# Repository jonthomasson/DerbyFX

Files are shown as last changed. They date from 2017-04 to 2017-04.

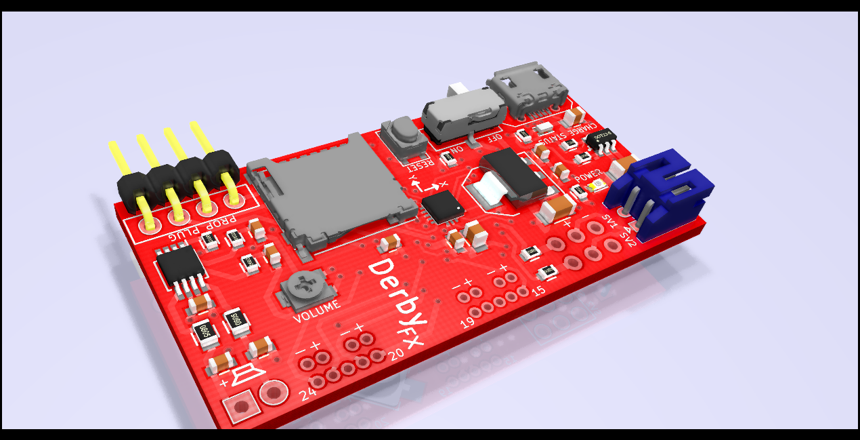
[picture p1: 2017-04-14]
rev1.b/derbyFX_raytrace.png

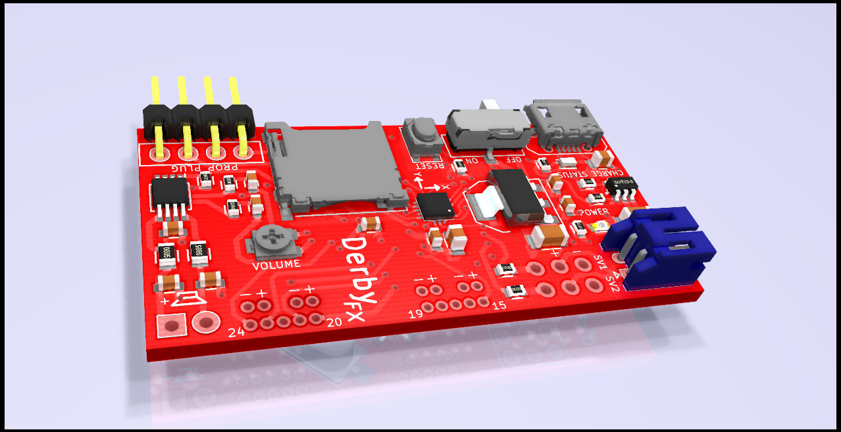
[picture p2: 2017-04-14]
rev1.b/derbyFX_rev1.b.png

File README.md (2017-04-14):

# DerbyFX
This small board provides a development platform for a pinewood derby car. It sports an accelerometer, an sd card, a charge circuit for an external lithium ion battery, an audio amp, 2 servo plugs, a speaker connector, and 10 gpio pins. At the heart of the board is a Parallax Propeller microcontroller.

![CPLD running in breadboard](https://lh3.googleusercontent.com/XKKODQA45qIu_XWEh1ipbHdZi0rYT_jDOUO9jJZsp1Ay5FmV7U-XDJ-tHK5IJP2ZgFuQk_qfYUtz5T6PSdiaZT0pmwx6YwFBaJhmt29JHCF6nIpZZk6bQHzHcNKXj_aoYBd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)

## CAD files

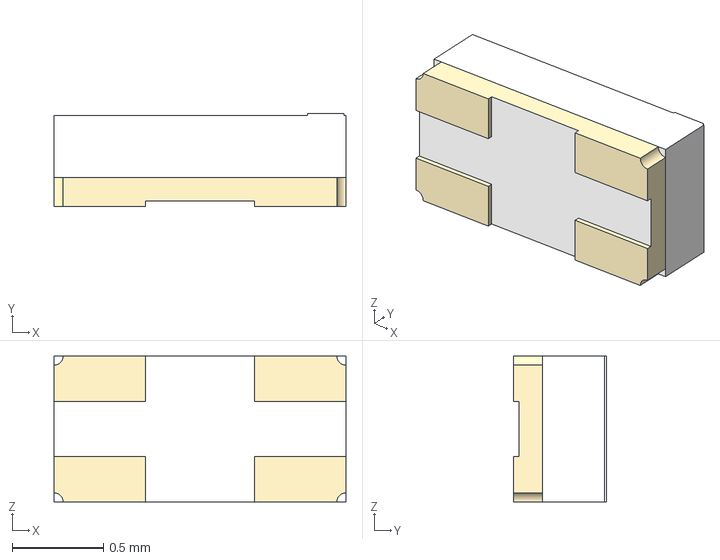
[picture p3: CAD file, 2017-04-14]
rev1.b/3dmodels/HSMF_C16X.step
1.60 x 0.51 x 0.8 mm

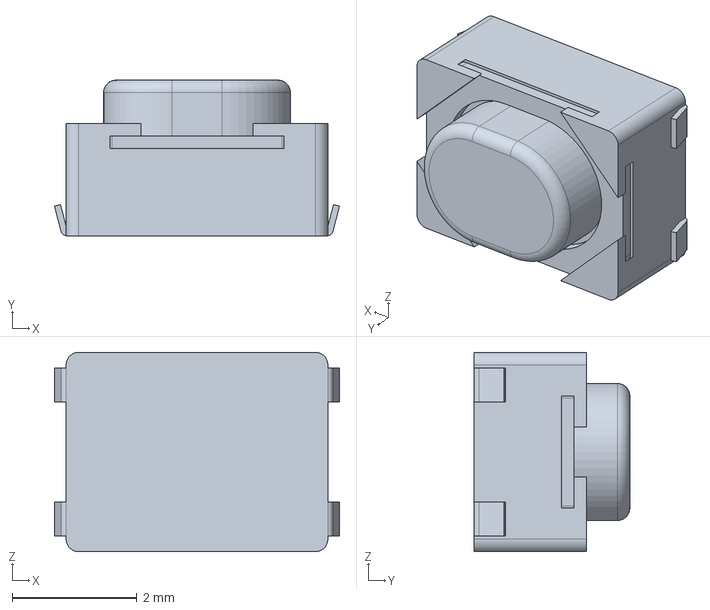
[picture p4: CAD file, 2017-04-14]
rev1.b/3dmodels/PTS810.stp
4.58 x 2.50 x 3.20 mm

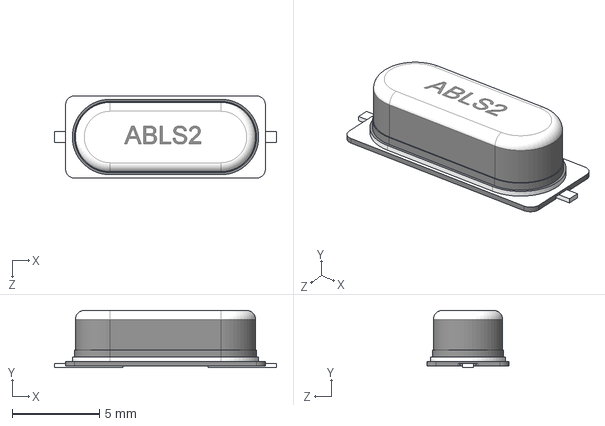
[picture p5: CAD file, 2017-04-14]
rev1.b/3dmodels/ABLS2.STEP
12.7 x 3.27 x 4.70 mm

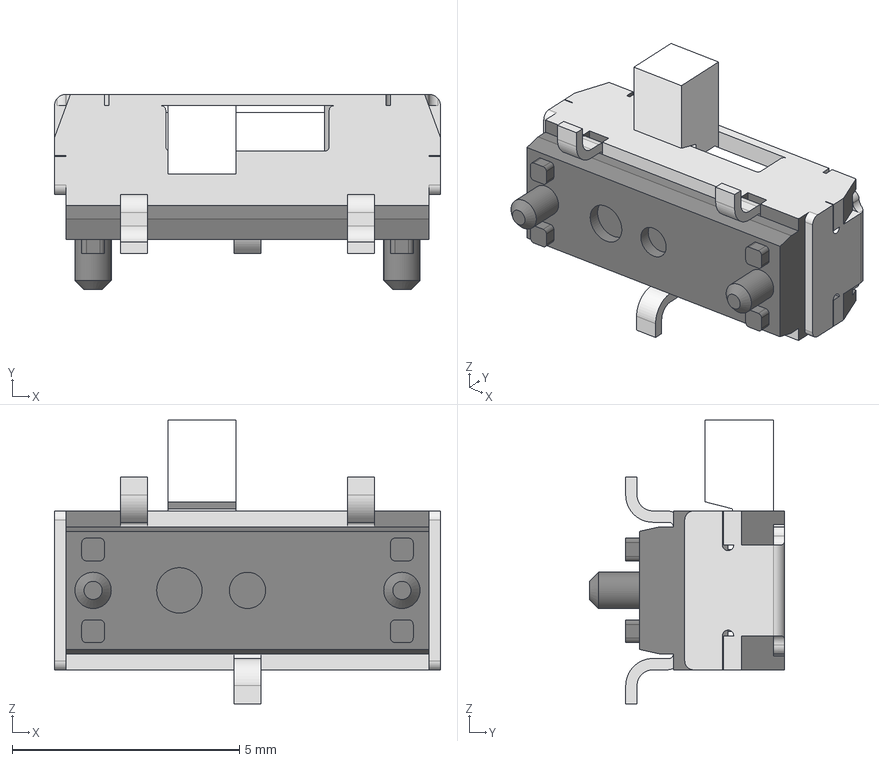
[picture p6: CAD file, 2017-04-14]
rev1.b/3dmodels/CL-SB-12B-11T.stp
8.50 x 4.30 x 6.25 mm
_12B-11_c
_2Side setting_s

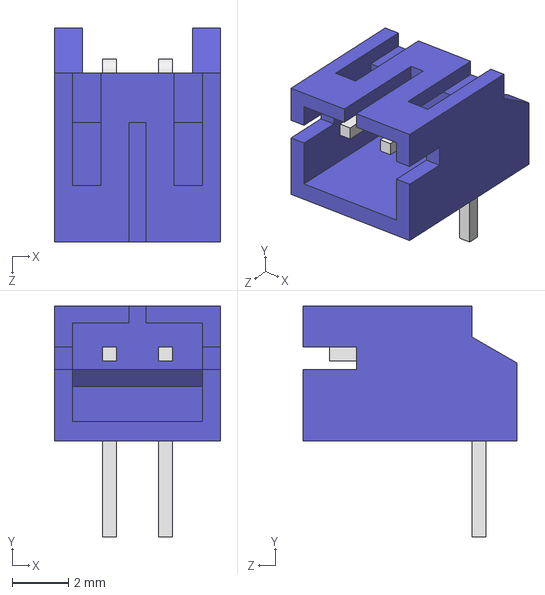
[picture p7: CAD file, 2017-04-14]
rev1.b/3dmodels/S2B-PH-K-S.STEP
5.90 x 8.20 x 7.60 mm

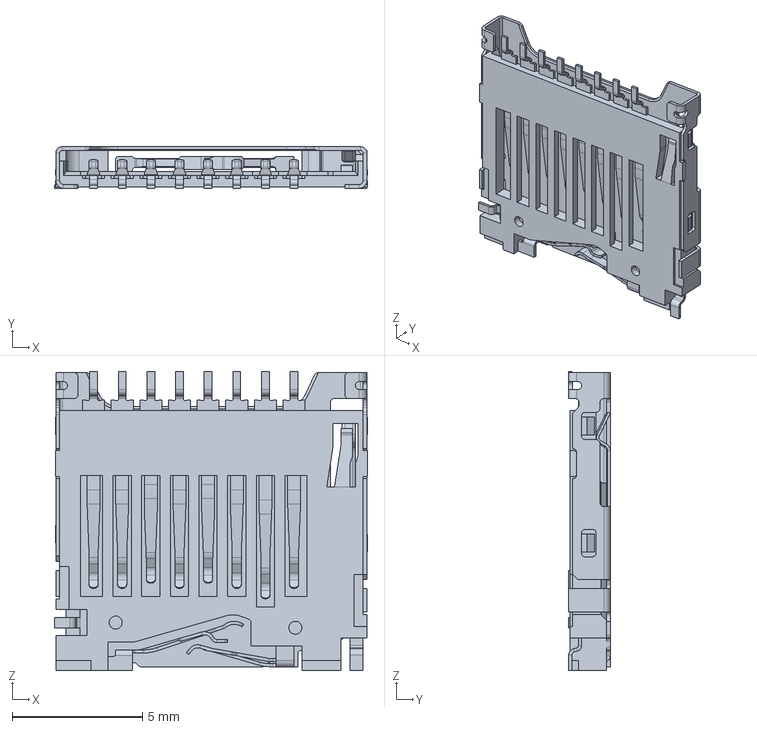
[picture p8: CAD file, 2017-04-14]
rev1.b/3dmodels/1140084168-revB.stp
12.0 x 1.60 x 11.5 mm

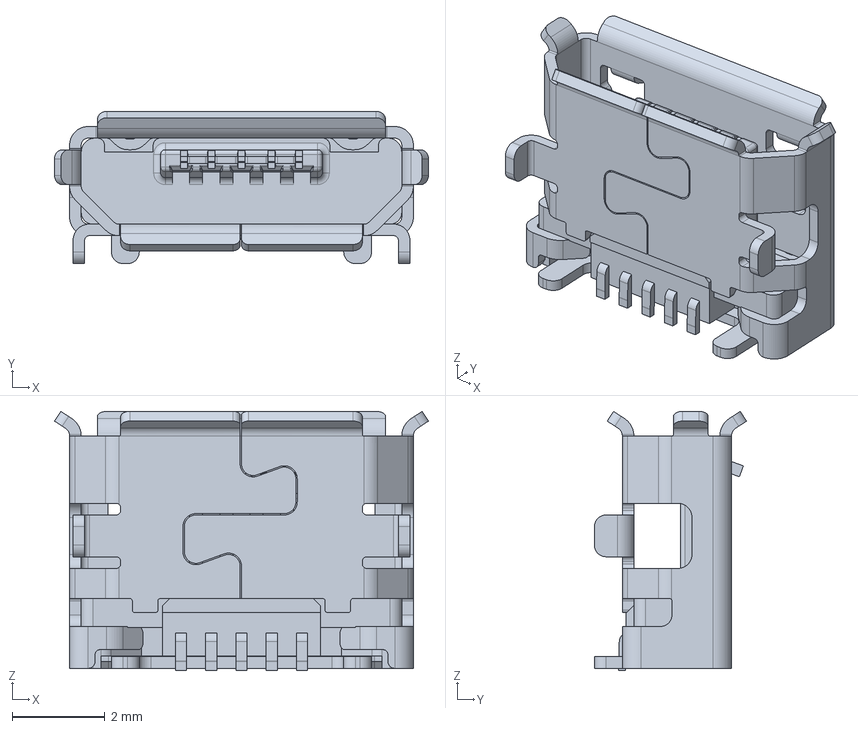
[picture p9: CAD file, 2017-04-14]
rev1.b/3dmodels/10118194c.stp
8.05 x 3.27 x 5.58 mm

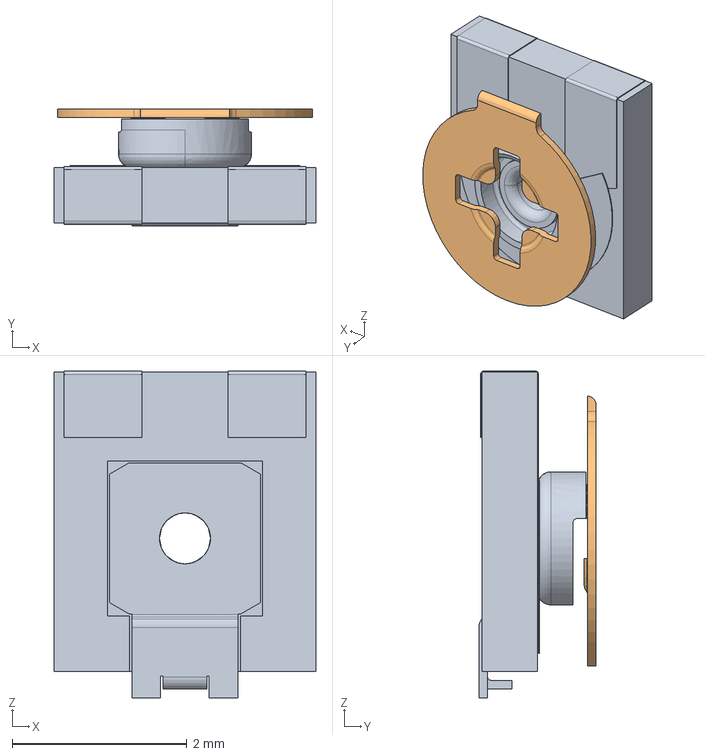
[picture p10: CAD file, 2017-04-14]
rev1.b/3dmodels/3303X003.stp
3.00 x 1.35 x 3.75 mm

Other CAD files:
rev1.b/3dmodels/User Library-HSMF-C16x.STEP
rev1.b/3dmodels/DM3D-SF.stp
rev1.b/3dmodels/ABLS2_revb.step
rev1.b/3dmodels/S2B_PH_K_S.step

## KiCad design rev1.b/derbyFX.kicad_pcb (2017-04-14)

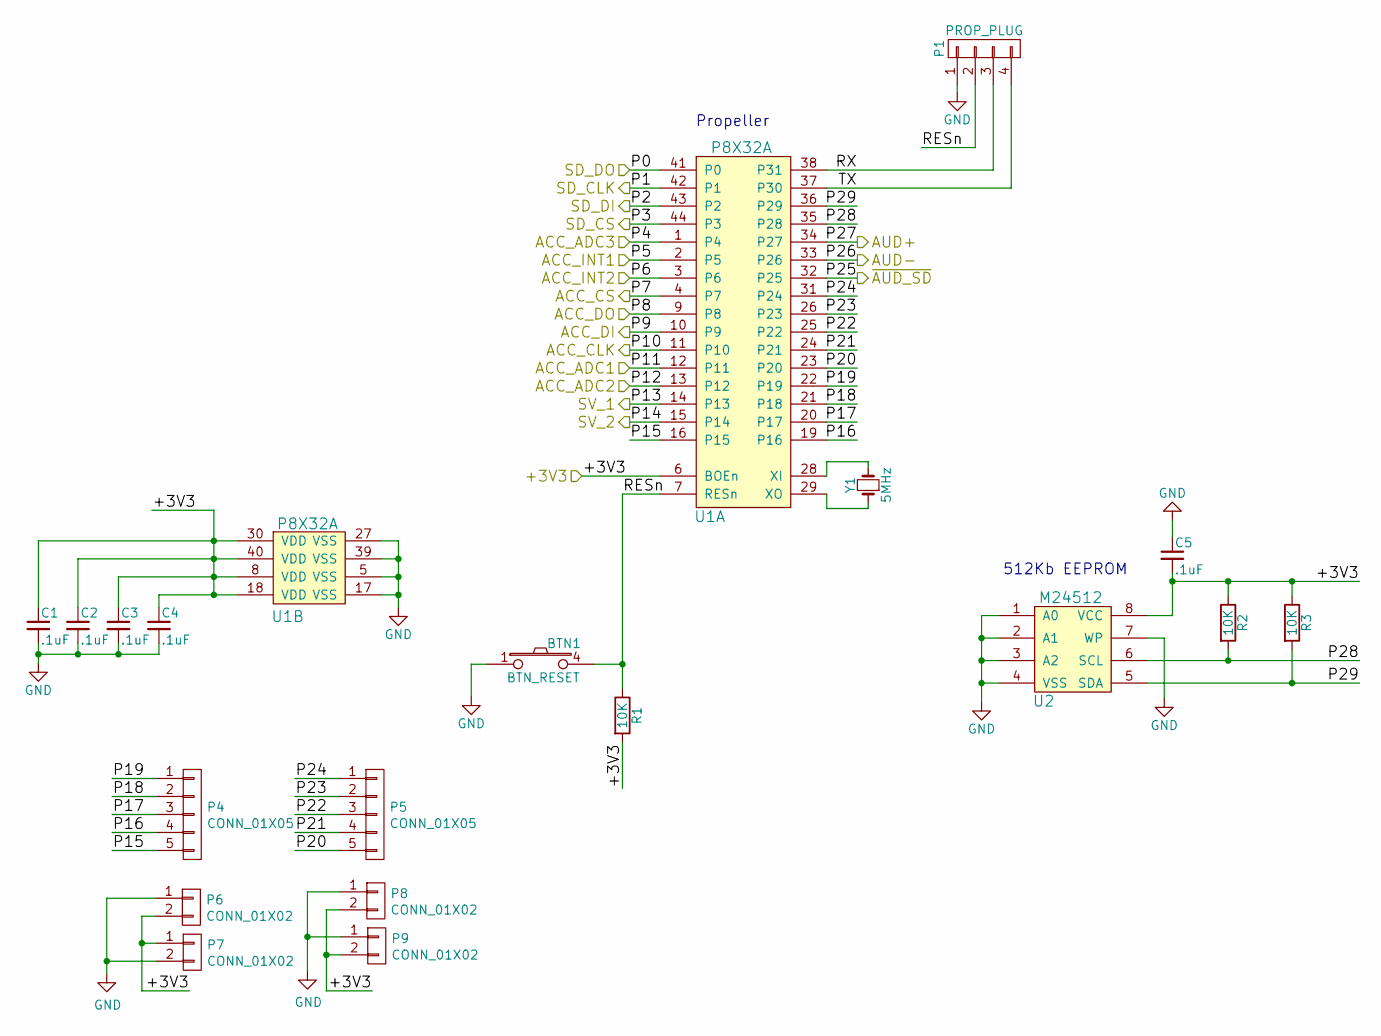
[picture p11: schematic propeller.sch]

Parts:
BTN1: BTN_RESET; SWITCH_PTS810
C1, C2, C3, C4, C5: .1uF; C_0603
P1: PROP_PLUG; Pin_Header_Angled_1x04
P4, P5: CONN_01X05; CONN_1_X_5_MINI
P6, P7, P8, P9: CONN_01X02; CONN_1_X_2_MINI
R1, R2, R3: 10K; R_0603
U1: P8X32A; LQFP-44_10x10mm_Pitch0.8mm
U2: M24512; SOIC-8_3.9x4.9mm_Pitch1.27mm
Y1: 5MHz; Crystal_HC49-SD_SMD

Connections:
/Sheet58820796/+3V3: C1.1, C2.1, C3.1, C4.1, C5.2, P6.2, P7.1, P8.2, P9.2, R1.2, R2.1, R3.1, U1.6 (BOEn), U1.8 (VDD), U1.18 (VDD), U1.30 (VDD), U1.40 (VDD), U2.8 (VCC); also elsewhere on the board
/Sheet58820796/ACC_ADC1: U1.12 (P11); also elsewhere on the board
/Sheet58820796/ACC_ADC2: U1.13 (P12); also elsewhere on the board
/Sheet58820796/ACC_ADC3: U1.1 (P4); also elsewhere on the board
/Sheet58820796/ACC_CLK: U1.11 (P10); also elsewhere on the board
/Sheet58820796/ACC_CS: U1.4 (P7); also elsewhere on the board
/Sheet58820796/ACC_DI: U1.10 (P9); also elsewhere on the board
/Sheet58820796/ACC_DO: U1.9 (P8); also elsewhere on the board
/Sheet58820796/ACC_INT1: U1.2 (P5); also elsewhere on the board
/Sheet58820796/ACC_INT2: U1.3 (P6); also elsewhere on the board
/Sheet58820796/AUD+: U1.34 (P27); also elsewhere on the board
/Sheet58820796/AUD-: U1.33 (P26); also elsewhere on the board
/Sheet58820796/P15: P4.5, U1.16 (P15)
/Sheet58820796/P16: P4.4, U1.19 (P16)
/Sheet58820796/P17: P4.3, U1.20 (P17)
/Sheet58820796/P18: P4.2, U1.21 (P18)
/Sheet58820796/P19: P4.1, U1.22 (P19)
/Sheet58820796/P20: P5.5, U1.23 (P20)
/Sheet58820796/P21: P5.4, U1.24 (P21)
/Sheet58820796/P22: P5.3, U1.25 (P22)
/Sheet58820796/P23: P5.2, U1.26 (P23)
/Sheet58820796/P24: P5.1, U1.31 (P24)
/Sheet58820796/P28: R2.2, U1.35 (P28), U2.6 (SCL)
/Sheet58820796/P29: R3.2, U1.36 (P29), U2.5 (SDA)
/Sheet58820796/RESn: BTN1.4, P1.2, R1.1, U1.7 (RESn)
/Sheet58820796/RX: P1.3, U1.38 (P31)
/Sheet58820796/SD_CLK: U1.42 (P1); also elsewhere on the board
/Sheet58820796/SD_CS: U1.44 (P3); also elsewhere on the board
/Sheet58820796/SD_DI: U1.43 (P2); also elsewhere on the board
/Sheet58820796/SD_DO: U1.41 (P0); also elsewhere on the board
/Sheet58820796/SV_1: U1.14 (P13); also elsewhere on the board
/Sheet58820796/SV_2: U1.15 (P14); also elsewhere on the board
/Sheet58820796/TX: P1.4, U1.37 (P30)
/Sheet58820796/~AUD_SD: U1.32 (P25); also elsewhere on the board
GND: BTN1.1, C1.2, C2.2, C3.2, C4.2, C5.1, P1.1, P6.1, P7.2, P8.1, P9.1, U1.5 (VSS), U1.17 (VSS), U1.27 (VSS), U1.39 (VSS), U2.1 (A0), U2.2 (A1), U2.3 (A2), U2.4 (VSS), U2.7 (WP); also elsewhere on the board
unnamed: U1.28 (XI), Y1.2
unnamed: U1.29 (XO), Y1.1

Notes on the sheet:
512Kb EEPROM
Propeller

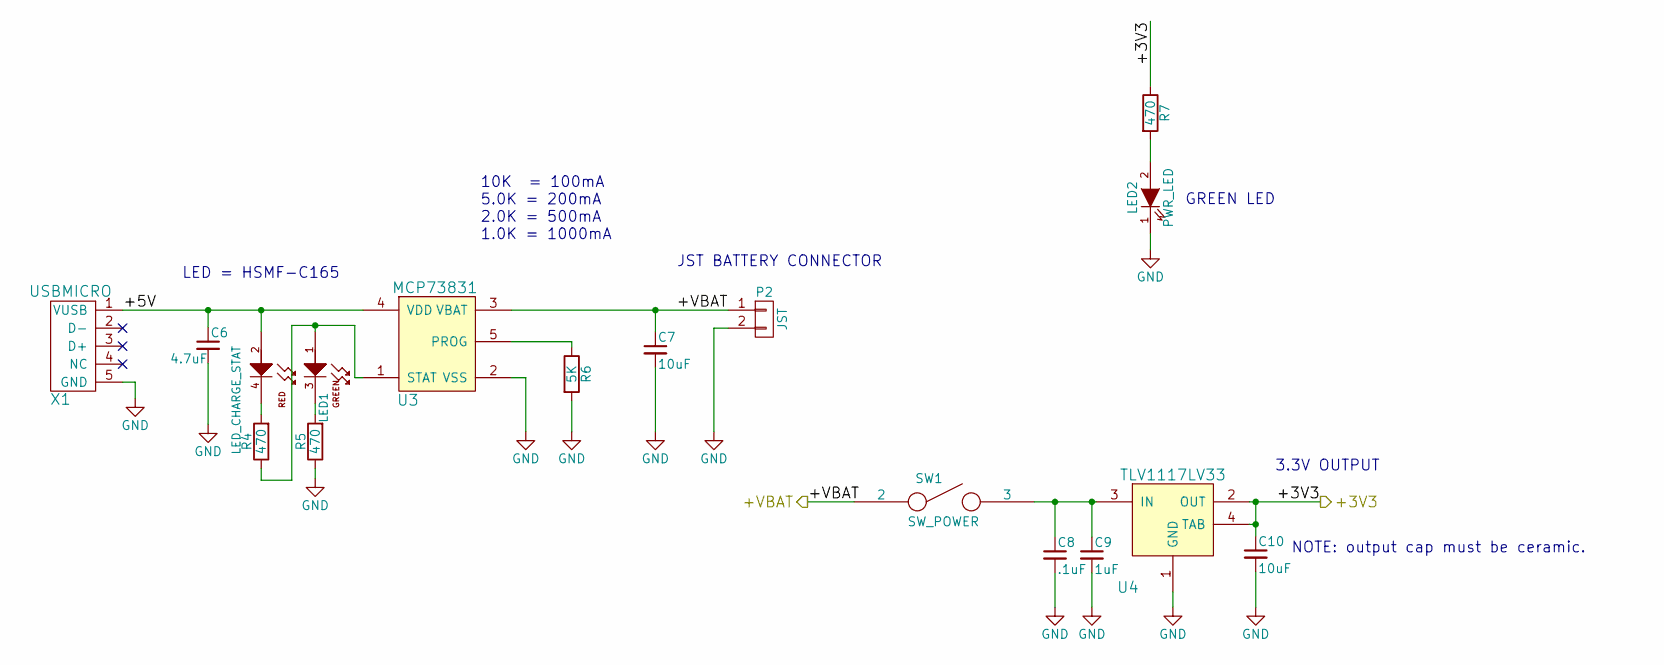
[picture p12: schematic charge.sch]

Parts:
C6: 4.7uF; C_0805
C7, C10: 10uF; C_1206
C8: .1uF; C_0603
C9: 1uF; C_0603
LED1: LED_CHARGE_STAT; LED_0603_HSMF_C165
LED2: PWR_LED; LED_0603
P2: JST; JST_PH_S2B-PH-K_02x2.00mm_Angled
R4, R5, R7: 470; R_0603
R6: 5K; R_0603
SW1: SW_POWER; SWITCH_CL_SB_12B
U3: MCP73831; SOT-23-5
U4: TLV1117LV33; SOT-223
X1: USBMICRO; MICRO_USB_10118194

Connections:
/Sheet588423CD/+5V: C6.1, LED1.2 (ANODE_RED), U3.4 (VDD), X1.1 (VUSB)
/Sheet588423CD/+VBAT: C7.1, P2.1, SW1.2, U3.3 (VBAT); also elsewhere on the board
/Sheet58820796/+3V3: C10.1, R7.1, U4.2 (OUT), U4.4 (TAB); also elsewhere on the board
GND: C6.2, C7.2, C8.2, C9.2, C10.2, LED2.1 (K), P2.2, R5.1, R6.2, U3.2 (VSS), U4.1 (GND), X1.5 (GND); also elsewhere on the board
unnamed: C8.1, C9.1, SW1.3, U4.3 (IN)
unnamed: LED1.1 (ANODE_GREEN), R4.1, U3.1 (STAT)
unnamed: LED1.3 (CATHODE_GREEN), R5.2
unnamed: LED1.4 (CATHODE_RED), R4.2
unnamed: LED2.2 (A), R7.2
unnamed: R6.1, U3.5 (PROG)

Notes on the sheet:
10K = 100mA 5.0K = 200mA 2.0K = 500mA 1.0K = 1000mA
JST BATTERY CONNECTOR
3.3V OUTPUT
NOTE: output cap must be ceramic.
GREEN LED
LED = HSMF-C165

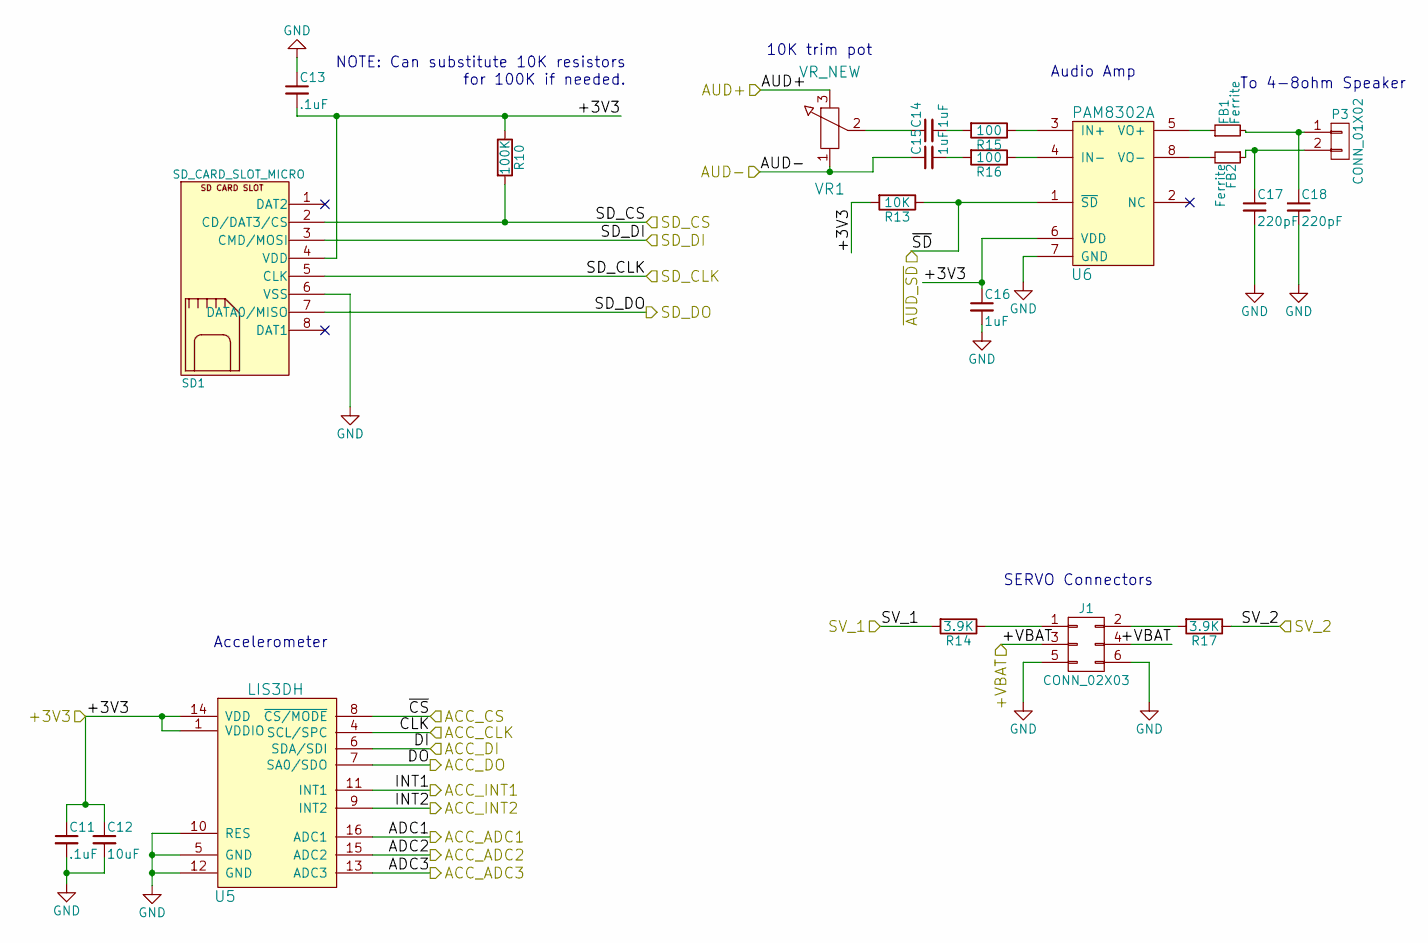
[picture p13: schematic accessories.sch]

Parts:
C11, C13: .1uF; C_0603
C12: 10uF; C_0805
C14, C15, C16: 1uF; C_0603
C17, C18: 220pF; C_0603
FB1, FB2: Ferrite; R_0805
J1: CONN_02X03; Pin_Header_Straight_2x03
P3: CONN_01X02; Pin_Header_Straight_1x02
R10: 100K; R_0603
R13: 10K; R_0603
R14, R17: 3.9K; R_0603
R15, R16: 100; R_0603
SD1: SD_CARD_SLOT_MICRO; MICRO_SD_1140084168
U5: LIS3DH; LGA_16_3x3
U6: PAM8302A; MSOP-8_3x3mm_Pitch0.65mm
VR1: VR_NEW; BOURNS_3303W

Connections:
/Sheet588423CD/+VBAT: J1.3, J1.4; also elsewhere on the board
/Sheet58820796/+3V3: C11.1, C12.1, C13.2, C16.1, R10.1, R13.2, SD1.4 (VDD), U5.1 (VDDIO), U5.14 (VDD), U6.6 (VDD); also elsewhere on the board
/Sheet58820796/ACC_ADC1: U5.16 (ADC1); also elsewhere on the board
/Sheet58820796/ACC_ADC2: U5.15 (ADC2); also elsewhere on the board
/Sheet58820796/ACC_ADC3: U5.13 (ADC3); also elsewhere on the board
/Sheet58820796/ACC_CLK: U5.4 (SCL/SPC); also elsewhere on the board
/Sheet58820796/ACC_CS: U5.8 (~CS/MODE); also elsewhere on the board
/Sheet58820796/ACC_DI: U5.6 (SDA/SDI); also elsewhere on the board
/Sheet58820796/ACC_DO: U5.7 (SA0/SDO); also elsewhere on the board
/Sheet58820796/ACC_INT1: U5.11 (INT1); also elsewhere on the board
/Sheet58820796/ACC_INT2: U5.9 (INT2); also elsewhere on the board
/Sheet58820796/AUD+: VR1.3; also elsewhere on the board
/Sheet58820796/AUD-: C15.1, VR1.1; also elsewhere on the board
/Sheet58820796/SD_CLK: SD1.5 (CLK); also elsewhere on the board
/Sheet58820796/SD_CS: R10.2, SD1.2 (CD/DAT3/CS); also elsewhere on the board
/Sheet58820796/SD_DI: SD1.3 (CMD/MOSI); also elsewhere on the board
/Sheet58820796/SD_DO: SD1.7 (DATA0/MISO); also elsewhere on the board
/Sheet58820796/SV_1: R14.2; also elsewhere on the board
/Sheet58820796/SV_2: R17.1; also elsewhere on the board
/Sheet58820796/~AUD_SD: R13.1, U6.1 (~SD); also elsewhere on the board
GND: C11.2, C12.2, C13.1, C16.2, C17.2, C18.2, J1.5, J1.6, SD1.6 (VSS), U5.5 (GND), U5.10 (RES), U5.12 (GND), U6.7 (GND); also elsewhere on the board
unnamed: C14.1, VR1.2
unnamed: C14.2, R15.2
unnamed: C15.2, R16.2
unnamed: C17.1, FB2.1, P3.2
unnamed: C18.1, FB1.2, P3.1
unnamed: FB1.1, U6.5 (VO+)
unnamed: FB2.2, U6.8 (VO-)
unnamed: J1.1, R14.1
unnamed: J1.2, R17.2
unnamed: R15.1, U6.3 (IN+)
unnamed: R16.1, U6.4 (IN-)

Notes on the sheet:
NOTE: Can substitute 10K resistors for 100K if needed.
To 4-8ohm Speaker
10K trim pot
SERVO Connectors
Accelerometer
Audio Amp

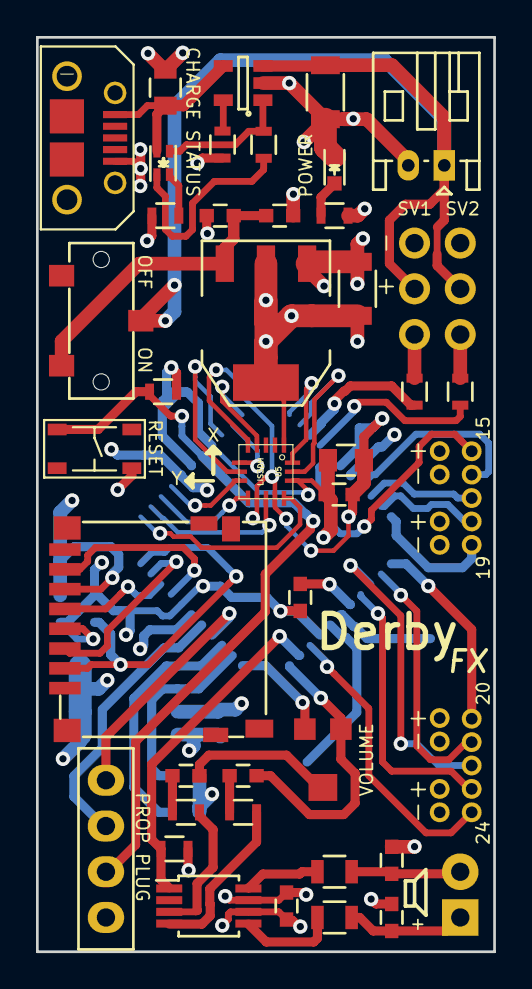
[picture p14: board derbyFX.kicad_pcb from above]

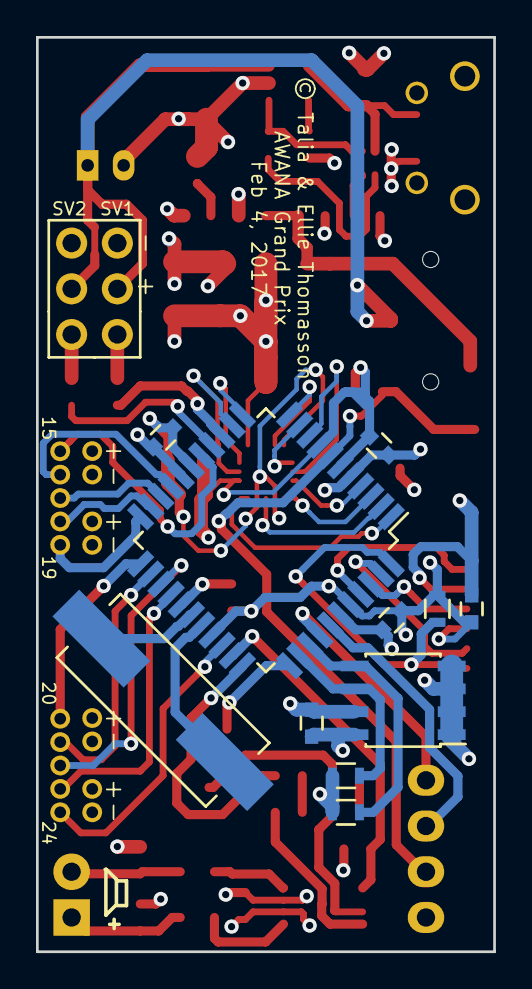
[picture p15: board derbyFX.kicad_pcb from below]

Board: 4 copper layers, 25.4 x 50.8 mm, 57 parts (12 on the bottom side), 56 nets.

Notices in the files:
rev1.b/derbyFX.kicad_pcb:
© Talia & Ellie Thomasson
